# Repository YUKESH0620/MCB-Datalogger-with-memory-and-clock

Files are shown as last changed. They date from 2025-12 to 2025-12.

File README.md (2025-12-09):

# MCU Datalogger with Memory and Real-Time Clock

A compact, low-power data-logging board designed in KiCad (v9.0.4). The board is built around an ATmega328P-AU microcontroller, a DS1337S real-time clock (RTC) with a 32.768 kHz crystal, and two 24LC1025 I²C EEPROM devices for extended timestamped data storage. The design is a 2-layer custom PCB sized 87.63mm × 39.116mm and is powered by a coin-cell battery (BT1) for RTC backup. Data can be accessed via I²C or UART; the MCU is programmable by ICSP or a UART bootloader.

---

## Overview

This project is a lightweight, modular data logger intended for timestamped sensor data collection. It provides:

- Reliable timekeeping (DS1337S with coin-cell backup)
- Extended non-volatile storage (two 24LC1025 EEPROMs)
- Standard interfaces for integration (I²C, UART, GPIO, ICSP)
- A compact 2-layer PCB designed in KiCad 9.0.4

---

## Features

- Microcontroller: ATmega328P-AU (16 MHz)
- Real-time clock: DS1337S with 32.768 kHz crystal
- Non-volatile memory: 2 × 24LC1025 EEPROM (I²C)
- Connectivity: I²C header, UART (RX/TX) header, GPIO header, 6-pin ICSP
- Indicators: 2 status LEDs
- Power: Coin-cell Battery (BT1) for RTC backup
- Board: 2-layer PCB; 87.63 mm × 39.116 mm; 4 mounting holes
- KiCad version: 9.0.0

---

## Hardware Architecture

High-level blocks:

- MCU (ATmega328P-AU): central controller for data acquisition, timestamping, and storage
- RTC (DS1337S): battery-backed real-time clock (I²C)
- EEPROMs (2 × 24LC1025): extended I²C non-volatile storage
- Headers: I²C, UART, GPIO, and ICSP for programming and peripherals
- Power: Coin-cell for RTC backup; decoupling and power filtering on-board

Notable electrical details:

- MCU clock: 16 MHz crystal (Y2) with C2 = 22 pF and C3 = 22 pF
- RTC: DS1337S with 32.768 kHz crystal; pull-ups R1 = 10 kΩ, R2 = 10 kΩ; decoupling C1 = 0.1 µF
- EEPROMs: Two 24LC1025 on I²C with pull-ups R3 = 4.7 kΩ and R4 = 4.7 kΩ
- Status LEDs: D1 (R5 = 330 Ω), D2 (R7 = 330 Ω)
- Power decoupling: C4 = 0.1 µF

---

## Schematic

- Schematic Page 1 — Main MCU, RTC, EEPROM



- Schematic Page 2 — Connectors



Refer to the KiCad schematic files in the repo for full net names, pin labels, and design notes.

---

## PCB Layout
### 2 layer



### 4 layer

  
### 3D View



#### PCB summary

| Property | Value |
|---|---:|
| Layers | 2 |
| Dimensions | 87.63 mm × 39.116 mm |
| Mounting holes | 4 |
| Silkscreen | Labeled pins (I²C, UART, GPIO, ICSP) |
| Unrouted nets | 0 |
| KiCad version | 9.0 |

---

## Connectors / Pinout

- I²C header (4-pin): SDA, SCL, VCC, GND
- UART header (3-pin): RX, TX, GND (VCC optional)
- GPIO header: multiple MCU GPIO pins broken out (see schematic)
- ICSP (6-pin): MISO, MOSI, SCK, RESET, VCC, GND

---

## Bill of Materials (BOM)

| Ref | Qty | Part | Notes |
|---|---:|---|---|
| U1 | 1 | ATmega328P-AU | 28-pin TQFP |
| U2 | 1 | DS1337S | RTC (I²C) |
| U3, U4 | 2 | 24LC1025 | I²C EEPROM |
| Y2 | 1 | Crystal | 16 MHz (MCU) |
| Y1 | 1 | Crystal | 32.768 kHz (RTC) |
| BT1 | 1 | Battery | CR2032 or equivalent (observe polarity) |
| C1, C4 | 2 | 0.1 µF | Ceramic decoupling caps |
| C2, C3 | 2 | 22 pF | Crystal load caps |
| R1, R2 | 2 | 10 kΩ | RTC pull-ups |
| R3, R4 | 2 | 4.7 kΩ | EEPROM pull-ups |
| R5, R7 | 2 | 330 Ω | LED current-limiting |
| D1, D2 | 2 | LED | SMD or THT per footprint |
| J1 (I²C) | 1 | Header | 4-pin |
| J2 (UART) | 1 | Header | 3-pin |
| J3 (GPIO) | 1 | Header | n-pin |
| J4 (ICSP) | 1 | 6-pin ICSP | 2×3 2.54 mm |
| Mounting holes | 4 | M3 | Mechanical mounting |

Full, exportable BOM (CSV) and placement files are provided in the repo (see /bom and /fab folders if present).

---

## How to Use

Assembly:

- Solder SMD components first (MCU, RTC, EEPROMs, resistors, capacitors), then through-hole parts (headers, coin cell holder).
- Observe polarity for LEDs and coin cell.
- Place crystals and load capacitors as shown in schematic.

Power:

- Supply VCC according to the chosen components (3.3 V or 5 V depending on populated parts). Confirm the RTC and EEPROM voltage ranges before applying power.
- Coin cell provides RTC backup via the VBAT connection on the DS1337S. Ensure correct polarity and secure holder.

Basic operation:

- The MCU collects sensor data (I²C/GPIO), requests current time from the DS1337S, and writes time-stamped entries to the EEPROM(s).
- Retrieve logs via UART (connect a USB‑to‑TTL adapter: RX→TX, TX→RX, GND→GND) at the baud rate set by the firmware.
- Optionally access EEPROMs directly over I²C from a host microcontroller or logic analyzer.

I²C notes:

- On-board pull-ups are provided (R1/R2 for RTC, R3/R4 for EEPROM). If your external bus already includes pull-ups, verify combined pull-up resistance is within recommended limits.
- Addressing: consult the 24LC1025 datasheet for device addressing and block management if both EEPROMs use similar address pins.

---

## Programming the MCU

ICSP (recommended for initial programming and bootloader burn):

- Connect a 6-pin ISP programmer (USBasp, AVRISP, etc.) to the ICSP header: MISO, MOSI, SCK, RESET, VCC, GND.
- Example avrdude command (USBasp):

  avrdude -c usbasp -p m328p -U flash:w:firmware.hex

UART (if a bootloader is installed):

- Use a USB‑to‑TTL adapter to the UART header. Typical Arduino/Optiboot settings for 16 MHz apply if using Arduino core.
- To burn a bootloader via Arduino IDE, connect an ISP programmer and select the appropriate board/frequency, then Tools → Burn Bootloader.

Firmware recommendations:

- Implement time queries to DS1337S via I²C and write structured records to EEPROM with checksums.
- Implement wear-leveling or a ring-buffer log scheme to maximize EEPROM lifespan.
- Provide a simple UART command set for log extraction and configuration.

---

<!--## Testing & Validation

- Verify MCU oscillator and boot behavior after programming.
- Confirm RTC register reads/writes and timekeeping across coin-cell swaps.
- Use an I²C scanner to validate device addresses for RTC and EEPROMs.
- Test UART responses and data export functionality. -->

## Future Improvements

- Add optional power domain/regulator for external supplies with coin-cell backup for RTC.
- Add battery charging and low-battery detection circuitry.
- Add footprints for common sensors (temperature, humidity, pressure) on-board.
- Implement hardware write-protect for EEPROMs and optional encryption of stored logs.
- Provide a 3D-printable enclosure and mounting guides.

---

## Contributing

Contributions are welcome. Please:

- Open an issue to discuss non-trivial changes before submitting a PR.
- Submit focused pull requests with updated KiCad files, Gerbers, and BOM when hardware changes are included.
- Keep commit messages clear and include rationale for electrical or layout changes.

---

## Safety

- Coin cells are a choking hazard and can be dangerous if swallowed—keep away from children.
- Handle ESD-sensitive parts with appropriate precautions.
- Verify coin-cell polarity before installing.

---

## License

This project is provided under the MIT License. See LICENSE for details.

---

## Contacts

For questions or collaboration, open an issue or contact the repository owner (YUKESH0620) via GitHub.

---

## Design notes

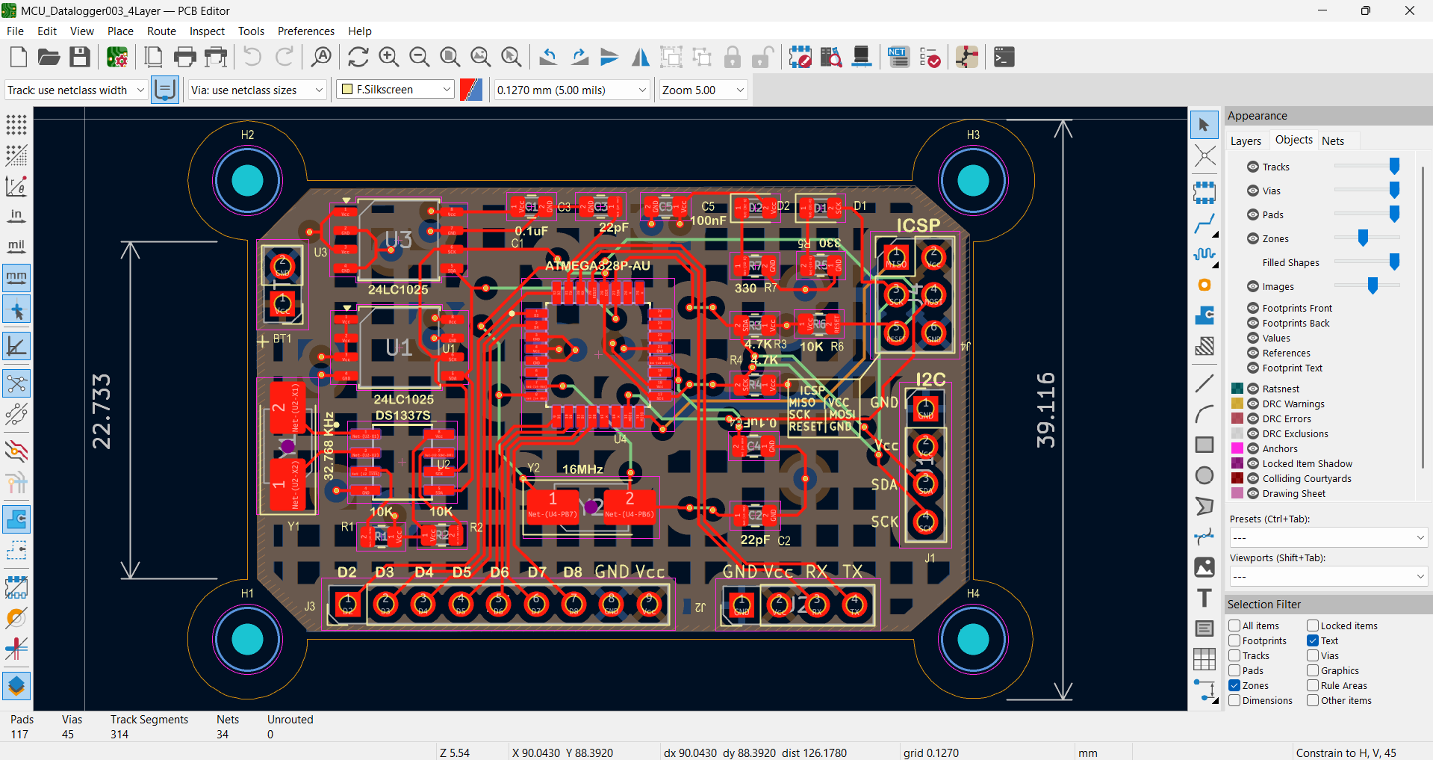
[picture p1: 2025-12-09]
Images/Screenshot 2025-12-07 205859.png

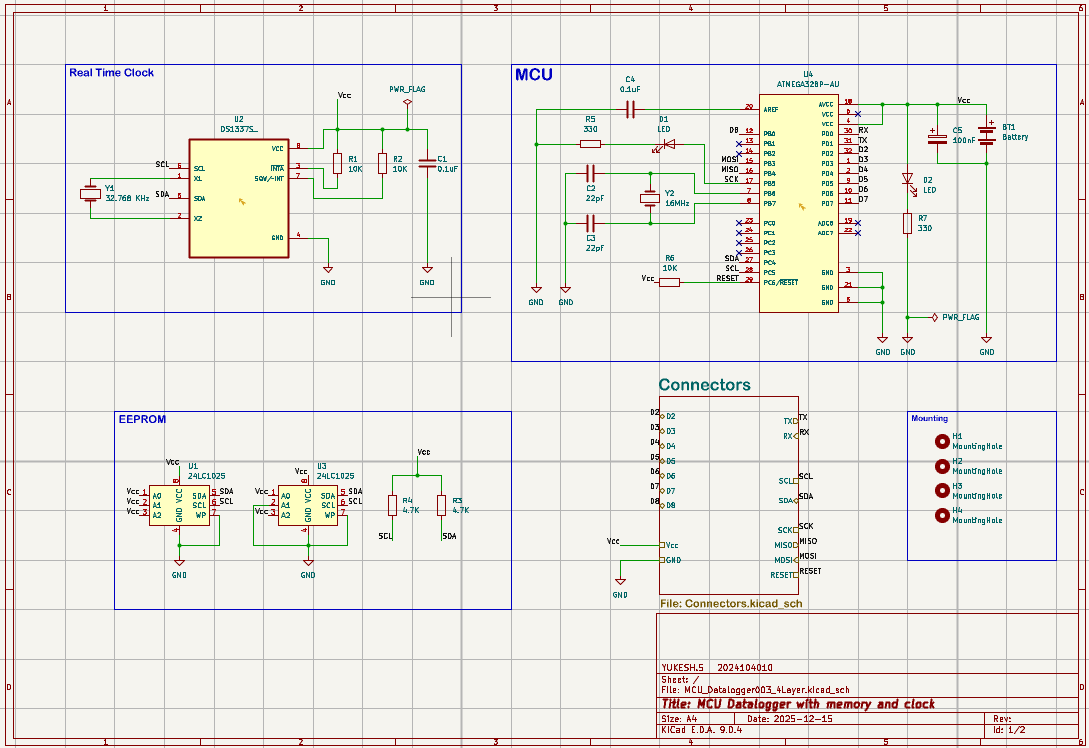
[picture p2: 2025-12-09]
Images/Screenshot 2025-12-07 232734.png

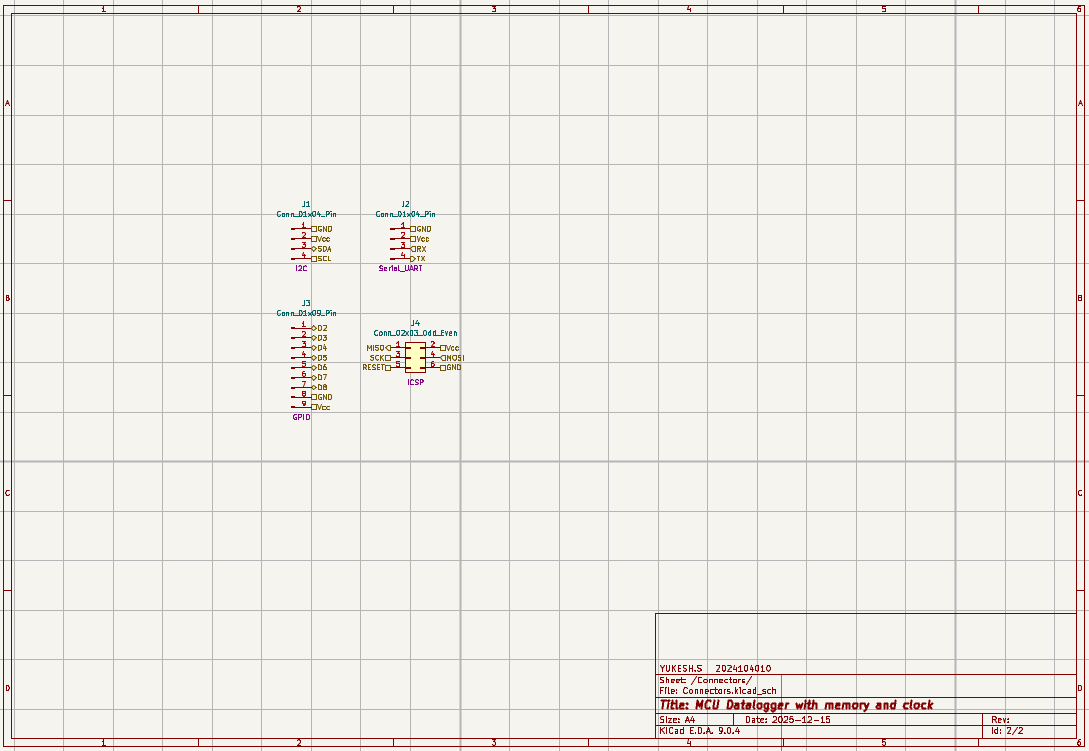
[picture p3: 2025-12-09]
Images/Screenshot 2025-12-07 232811.png

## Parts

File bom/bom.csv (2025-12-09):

Ref | Quantity | Part | Value/Notes | Footprint | Manufacturer | MPN
U1 | 1 | ATmega328P-AU | Microcontroller | TQFP-32 | Microchip | ATMEGA328P-AU
U2 | 1 | DS1337S | RTC (I2C) | SOIC-8 | Maxim | DS1337S
U3 | 1 | 24LC1025 | I2C EEPROM | SOIC-8 | Microchip | 24LC1025
U4 | 1 | 24LC1025 | I2C EEPROM | SOIC-8 | Microchip | 24LC1025
Y2 | 1 | Crystal | 16 MHz (MCU) | SMD | Various
Y1 | 1 | Crystal | 32.768 kHz (RTC) | SMD | Various
BT1 | 1 | Coin cell holder | CR2032 holder | Through-hole | Various
C1 | 1 | Capacitor | 0.1 uF | 0603 | Ceramic
C4 | 1 | Capacitor | 0.1 uF | 0603 | Ceramic
C2 | 1 | Capacitor | 22 pF | 0603 | Ceramic
C3 | 1 | Capacitor | 22 pF | 0603 | Ceramic
R1 | 1 | Resistor | 10 kOhm (RTC pull-up) | 0603 | Various
R2 | 1 | Resistor | 10 kOhm (RTC pull-up) | 0603 | Various
R3 | 1 | Resistor | 4.7 kOhm (EEPROM pull-up) | 0603 | Various
R4 | 1 | Resistor | 4.7 kOhm (EEPROM pull-up) | 0603 | Various
R5 | 1 | Resistor | 330 Ohm (LED) | 0603 | Various
R7 | 1 | Resistor | 330 Ohm (LED) | 0603 | Various
D1 | 1 | LED | Status LED | SMD-0805 | Various
D2 | 1 | LED | Status LED | SMD-0805 | Various
J1 | 1 | Header | I2C 4-pin | Header-1x4 | Various
J2 | 1 | Header | UART 3-pin | Header-1x3 | Various
J3 | 1 | Header | GPIO header | Header-1xN | Various
J4 | 1 | Header | ICSP 6-pin (2x3) | 2x3 2.54mm | Various
MH1 | 4 | Mounting hole | M3 mounting hole | Mechanical | Various

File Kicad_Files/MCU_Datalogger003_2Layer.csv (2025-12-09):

Id | Designator | Footprint | Quantity | Designation | Supplier and ref
1 | J4 | PinHeader_2x03_P2.54mm_Vertical | 1 | Conn_02x03_Odd_Even
2 | R7,R5 | R_0805_2012Metric | 2 | 330
3 | D1,D2 | LED_0805_2012Metric | 2 | LED
4 | R6,R1,R2 | R_0805_2012Metric | 3 | 10K
5 | C1,C4 | C_0805_2012Metric | 2 | 0.1uF
6 | C3,C2 | C_0805_2012Metric | 2 | 22pF
7 | U3,U1 | SOIC-8_5.3x5.3mm_P1.27mm | 2 | 24LC1025
8 | R3,R4 | R_0805_2012Metric | 2 | 4.7K
9 | BT1 | PinHeader_1x02_P2.54mm_Vertical | 1 | Battery
10 | U2 | RT-CLOCK_SOIC127P600X175-8N | 1 | DS1337S_
11 | U4 | ATMEGA328P-AUQFP80P900X900X120-32N | 1 | ATMEGA328P-AU
12 | J3 | PinHeader_1x09_P2.54mm_Vertical | 1 | Conn_01x09_Pin
13 | Y1 | Crystal_SMD_5032-2Pin_5.0x3.2mm_HandSoldering | 1 | 32.768 KHz
14 | Y2 | Crystal_SMD_5032-2Pin_5.0x3.2mm_HandSoldering | 1 | 16MHz
15 | J2,J1 | PinHeader_1x04_P2.54mm_Vertical | 2 | Conn_01x04_Pin
16 | C5 | C_0805_2012Metric | 1 | 100nF

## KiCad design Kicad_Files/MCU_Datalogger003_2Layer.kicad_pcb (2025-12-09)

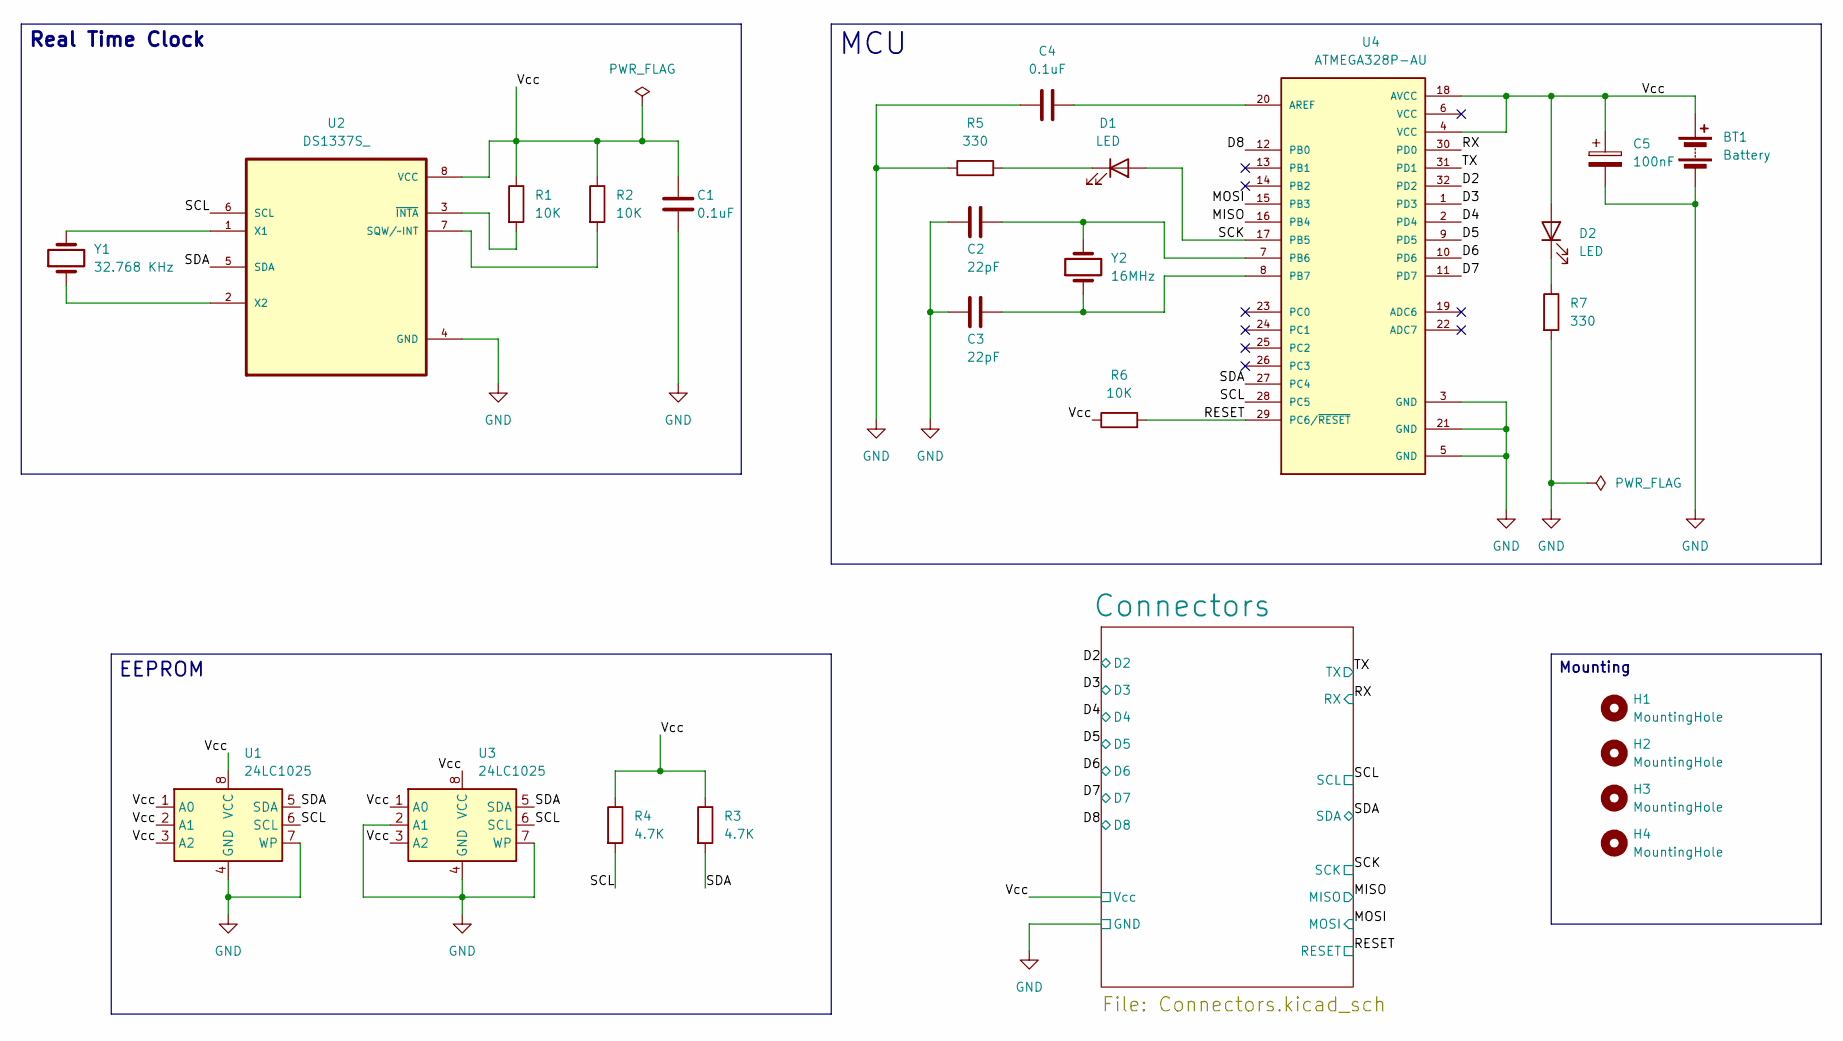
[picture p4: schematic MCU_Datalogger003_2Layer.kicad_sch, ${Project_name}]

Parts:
BT1: Battery; PinHeader_1x02_P2.54mm_Vertical
C1, C4: 0.1uF; C_0805_2012Metric
C2, C3: 22pF; C_0805_2012Metric
C5: 100nF; C_0805_2012Metric
D1, D2: LED; LED_0805_2012Metric
H1, H2, H3, H4: MountingHole; MountingHole_2.1mm
R1, R2, R6: 10K; R_0805_2012Metric
R3, R4: 4.7K; R_0805_2012Metric
R5, R7: 330; R_0805_2012Metric
U1, U3: 24LC1025; SOIC-8_5.3x5.3mm_P1.27mm
U2: DS1337S_; RT-CLOCK_SOIC127P600X175-8N
U4: ATMEGA328P-AU; ATMEGA328P-AUQFP80P900X900X120-32N; PARTREV 8271A
Y1: 32.768 KHz; Crystal_SMD_5032-2Pin_5.0x3.2mm_HandSoldering
Y2: 16MHz; Crystal_SMD_5032-2Pin_5.0x3.2mm_HandSoldering

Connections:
/D2: U4.32 (PD2); also elsewhere on the board
/D3: U4.1 (PD3); also elsewhere on the board
/D4: U4.2 (PD4); also elsewhere on the board
/D5: U4.9 (PD5); also elsewhere on the board
/D6: U4.10 (PD6); also elsewhere on the board
/D7: U4.11 (PD7); also elsewhere on the board
/D8: U4.12 (PB0); also elsewhere on the board
/MISO: U4.16 (PB4); also elsewhere on the board
/MOSI: U4.15 (PB3); also elsewhere on the board
/RESET: R6.2, U4.29 (PC6/~RESET); also elsewhere on the board
/RX: U4.30 (PD0); also elsewhere on the board
/SCK: D1.2 (A), U4.17 (PB5); also elsewhere on the board
/SCL: R4.2, U1.6 (SCL), U2.6 (SCL), U3.6 (SCL), U4.28 (PC5); also elsewhere on the board
/SDA: R3.2, U1.5 (SDA), U2.5 (SDA), U3.5 (SDA), U4.27 (PC4); also elsewhere on the board
/TX: U4.31 (PD1); also elsewhere on the board
/Vcc: BT1.1 (+), C1.1, C5.1, D2.2 (A), R1.1, R2.1, R3.1, R4.1, R6.1, U1.1 (A0), U1.2 (A1), U1.3 (A2), U1.8 (VCC), U2.8 (VCC), U3.1 (A0), U3.3 (A2), U3.8 (VCC), U4.4 (VCC), U4.18 (AVCC); also elsewhere on the board
GND: BT1.2 (-), C1.2, C2.2, C3.2, C4.1, C5.2, R5.1, R7.2, U1.4 (GND), U1.7 (WP), U2.4 (GND), U3.2 (A1), U3.4 (GND), U3.7 (WP), U4.3 (GND), U4.5 (GND), U4.21 (GND); also elsewhere on the board
unnamed: D1.1 (K), R5.2
unnamed: D2.1 (K), R7.1
unnamed: R2.2, U2.7 (SQW/~INT)
unnamed: U2.1 (X1), Y1.2
unnamed: U2.2 (X2), Y1.1
unnamed: R1.2, U2.3 (~INTA)
unnamed: C4.2, U4.20 (AREF)
unnamed: C2.1, U4.7 (PB6), Y2.2
unnamed: C3.1, U4.8 (PB7), Y2.1

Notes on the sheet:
EEPROM
Mounting
Real Time Clock
MCU

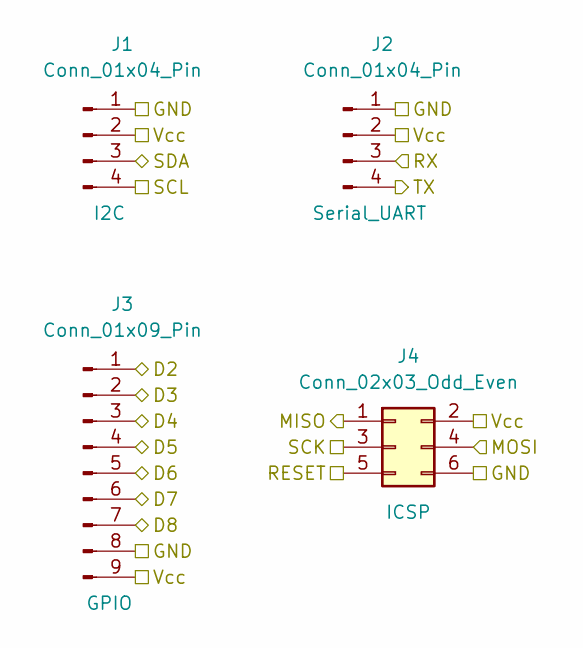
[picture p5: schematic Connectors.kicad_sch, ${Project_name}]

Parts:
J1, J2: Conn_01x04_Pin; PinHeader_1x04_P2.54mm_Vertical
J3: Conn_01x09_Pin; PinHeader_1x09_P2.54mm_Vertical
J4: Conn_02x03_Odd_Even; PinHeader_2x03_P2.54mm_Vertical

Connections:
/D2: J3.1; also elsewhere on the board
/D3: J3.2; also elsewhere on the board
/D4: J3.3; also elsewhere on the board
/D5: J3.4; also elsewhere on the board
/D6: J3.5; also elsewhere on the board
/D7: J3.6; also elsewhere on the board
/D8: J3.7; also elsewhere on the board
/MISO: J4.1; also elsewhere on the board
/MOSI: J4.4; also elsewhere on the board
/RESET: J4.5; also elsewhere on the board
/RX: J2.3; also elsewhere on the board
/SCK: J4.3; also elsewhere on the board
/SCL: J1.4; also elsewhere on the board
/SDA: J1.3; also elsewhere on the board
/TX: J2.4; also elsewhere on the board
/Vcc: J1.2, J2.2, J3.9, J4.2; also elsewhere on the board
GND: J1.1, J2.1, J3.8, J4.6; also elsewhere on the board

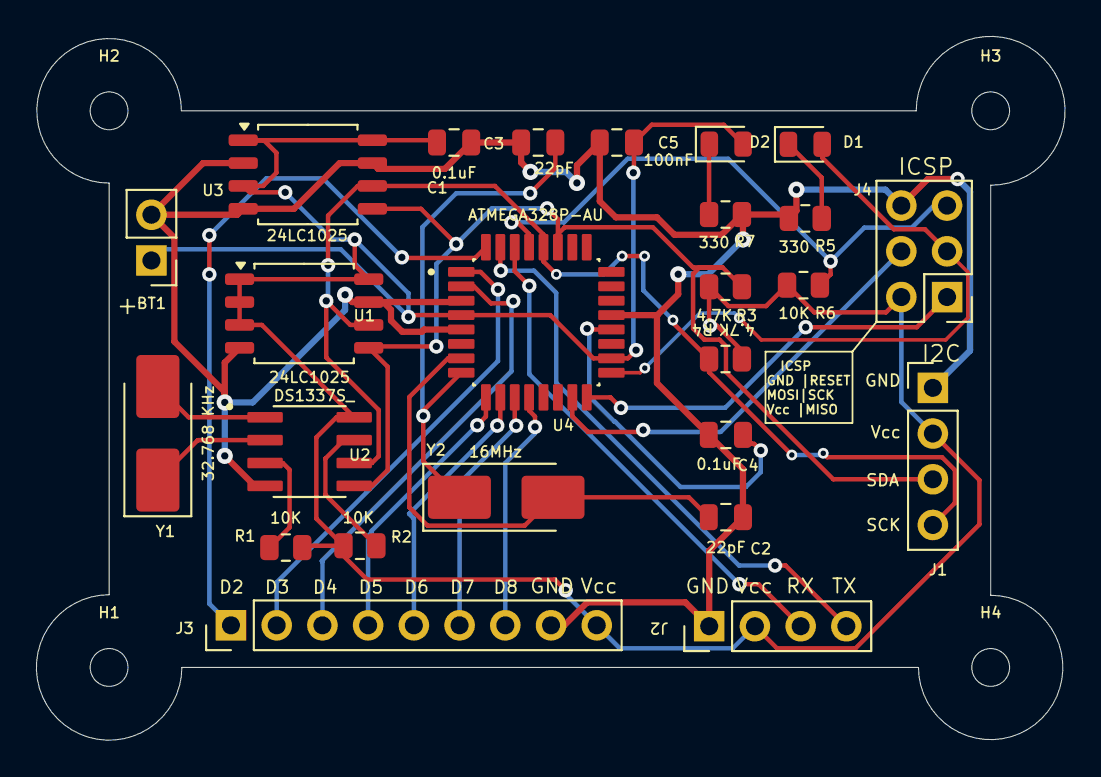
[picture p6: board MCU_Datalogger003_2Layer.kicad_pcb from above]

Board: 2 copper layers, 57.1 x 39.1 mm, 29 parts (0 on the bottom side), 26 nets.

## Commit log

2025-12-09 Add BOM CSV
    [bom.csv]
2025-12-09 Create Gerber Files
2025-12-09 Rename Gerber Files to Gerber Files_2layer
2025-12-09 Update and rename MCU_Data logger003-B_Cu.gbr to Gerber_Files_2layer/MCU_Data logger003-B_Cu.gbr
    [MCU_Data logger003-B_Cu.gbr]
2025-12-09 Update and rename MCU_Data logger003-B_Mask.gbr to Gerber_Files_2layer /MCU_Data logger003-B_Mask.gbr
    [MCU_Data logger003-B_Mask.gbr]
